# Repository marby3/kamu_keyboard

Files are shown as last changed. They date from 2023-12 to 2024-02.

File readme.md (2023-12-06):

# Kamu Keyboard 

Kamu Keyboardは分割型の10%カラム・スタッガードキーボードです。  
キーボードを組み立てるために必要な部品は以下の通りです。  

- PCB   x1  
- ProMicro  x2  
- TRRSジャック  x2  
- タクトスイッチ    x2  
- スイッチソケット（Cherry MX） x10  
- OLED（オプション）    x2  
- アクリルプレート 2mm（トップ）    x2
- アクリルプレート 2mm（ボトム）    x2
- アクリルプレート 2mm（カバー）    x2
- M2 ネジ（皿ねじ以外で3mm以上5mm以下で）   x28
- M2 スペーサー 7mm x14

PCBは[kamu_keyboard_pcb]>[gerber]内にあるファイルをJLCPCBやElecrowなどで発注することで注文が可能です。（ZIPファイルがあるのでそれを利用すると良いです）  

アクリルプレートは[kamu_keyboard_pcb]>[Plate_data]内にあるファイルを遊舎工房やElecrowなどのアクリルカットサービスが可能な業者にて加工をお願いしてください。  
1つのファイルで1セット分が加工できるようにファイルを用意しています。  

組み立て手順は[Kamu Keyboardの組み立て方](/build_guide/buildguide.md)をご覧ください。

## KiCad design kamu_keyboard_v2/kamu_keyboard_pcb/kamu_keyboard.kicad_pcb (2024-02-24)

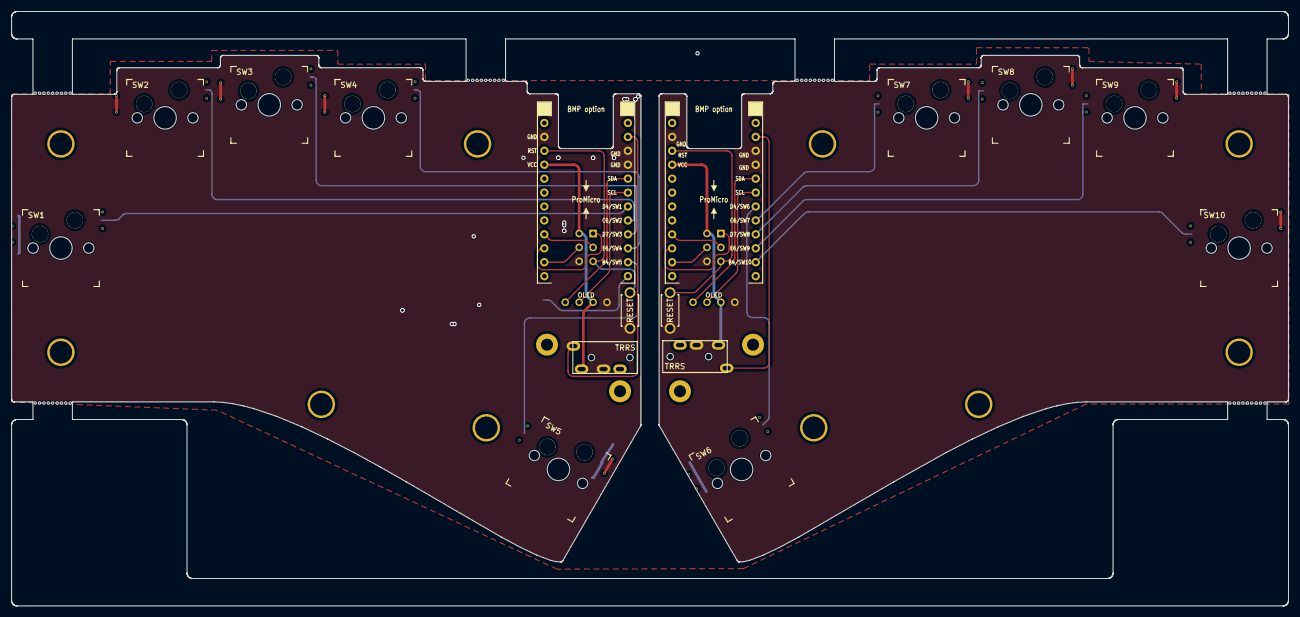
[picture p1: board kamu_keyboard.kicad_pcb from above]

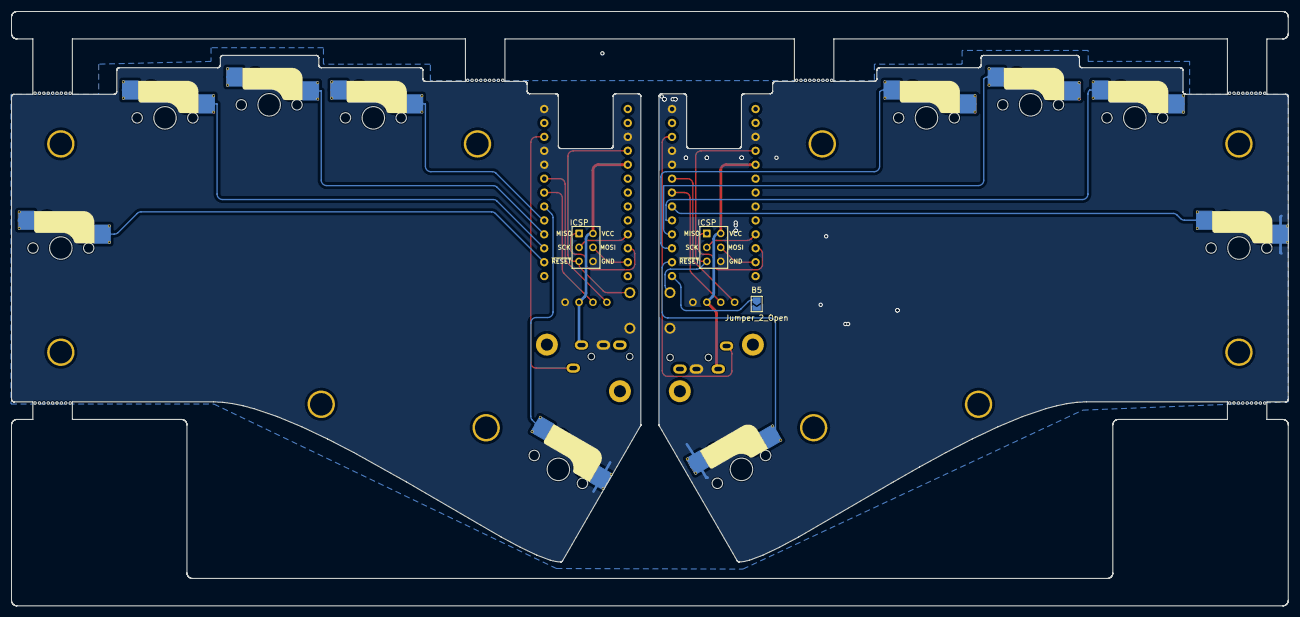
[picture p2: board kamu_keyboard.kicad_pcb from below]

Board: 2 copper layers, 232.9 x 108.4 mm, 21 parts (13 on the bottom side), 27 nets.

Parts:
J1, J3: OLED
J2, J4: ICSP
J5, J6: TRRS; MJ-4PP-9_1side
JP1: Jumper_2_Open; SolderJumper-2_P1.3mm_Open_TrianglePad1.0x1.5mm
RSW1, RSW2: SW_PUSH; ResetSW_1side
SW1, SW2, SW3, SW4, SW5, SW6, SW7, SW8, SW9, SW10: SW_PUSH; CherryMXSwitch_hotswap_1_00u
U1, U2: ProMicro; Board_BMP_Flip_Side

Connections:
/L_Data: J5.S, U1.2 (RX1/D2)
/L_MISO: J2.1, U1.15 (B3/14)
/L_MOSI: J2.4, U1.14 (B2/16)
/L_RST: J2.5, RSW1.2, U1.22 (RST)
/L_SCL: J1.2 (SCL), U1.6 (3/D0/SCL)
/L_SCLK: J2.3, U1.16 (B1/15)
/L_SDA: J1.1 (SDA), U1.5 (2/D1/SDA)
/L_push1: SW1.2, U1.7 (4/D4)
/L_push2: SW2.2, U1.8 (5/C6)
/L_push3: SW3.2, U1.9 (6/D7)
/L_push4: SW4.2, U1.10 (7/E6)
/L_push5: SW5.1, U1.11 (8/B4)
/L_side: JP1.1 (A), U1.12 (9/B5)
/R_Data: J6.S, U2.2 (RX1/D2)
/R_MISO: J4.1, U2.15 (B3/14)
/R_MOSI: J4.4, U2.14 (B2/16)
/R_RST: J4.5, RSW2.1, U2.22 (RST)
/R_SCL: J3.2 (SCL), U2.6 (3/D0/SCL)
/R_SCLK: J4.3, U2.16 (B1/15)
/R_SDA: J3.1 (SDA), U2.5 (2/D1/SDA)
/R_push6: SW6.2, U2.7 (4/D4)
/R_push7: SW7.1, U2.8 (5/C6)
/R_push8: SW8.1, U2.9 (6/D7)
/R_push9: SW9.1, U2.10 (7/E6)
/R_push10: SW10.1, U2.11 (8/B4)
GND: J1.4 (GND), J2.6, J3.4 (GND), J4.6, J5.R1, J6.R1, JP1.2 (B), RSW1.1, RSW2.2, SW1.1, SW2.1, SW3.1, SW4.1, SW5.2, SW6.1, SW7.2, SW8.2, SW9.2, SW10.2, U1.3 (GND), U1.4 (GND), U1.23 (GND), U1.26 (Bat-), U2.3 (GND), U2.4 (GND), U2.23 (GND), U2.26 (Bat-)
VCC: J1.3 (VCC), J2.2, J3.3 (VCC), J4.2, J5.T, J6.T, U1.21 (VCC), U2.21 (VCC)

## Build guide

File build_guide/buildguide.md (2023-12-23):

# Kamu Keyboardの組み立て方  

本ガイドはKamu KeyboardのV1を使用して作成されています。  
基本的な組み立て手順は同一ですので、部品を置き換えて組み立てをお願いします。  

# 必要部品  
- PCB   x1  
- ProMicro  x2  
- TRRSジャック  x2  
- タクトスイッチ    x2  
- スイッチソケット（Cherry MX） x10  
- OLED（オプション）    x2  
- アクリルプレート 2mm（トップ）    x2
- アクリルプレート 2mm（ボトム）    x2
- アクリルプレート 2mm（カバー）    x2
- M2 ネジ（皿ねじ以外で3mm以上5mm以下で）   x28
- M2 スペーサー 7mm x14

# 組み立て手順  

## 01. PCBの端材部分をカットする  
PCBの表面はこちらです。  
画像01  
PCBの裏面はこちらです。  
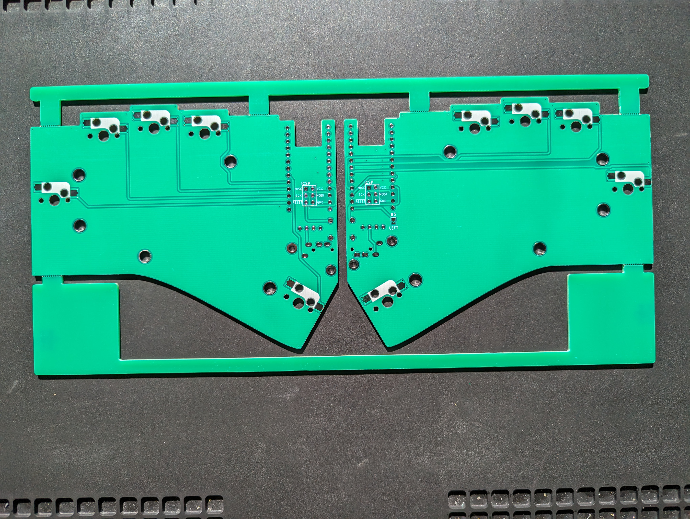
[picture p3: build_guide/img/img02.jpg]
画像02
  

端材部分をカットします。  
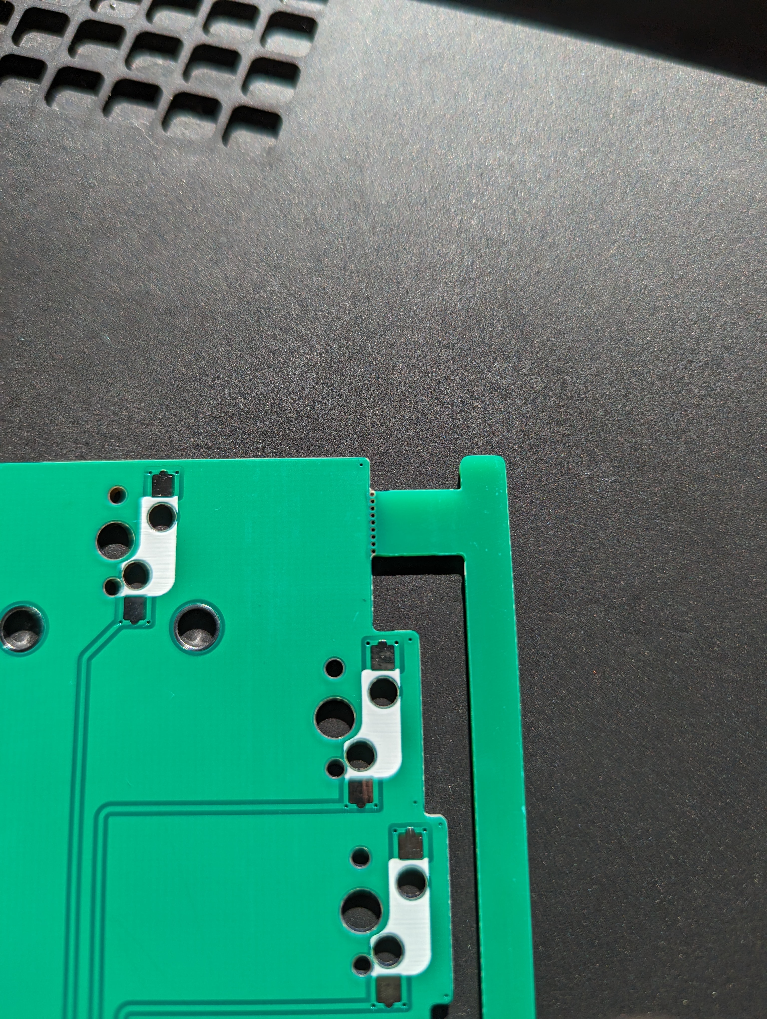
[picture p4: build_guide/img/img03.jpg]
画像03
  
該当箇所をヤスリ等で削ります。  
画像04  
画像05  

## 02. ソケットを半田付けする  
スイッチソケットのパッドに予備半田を行います。  
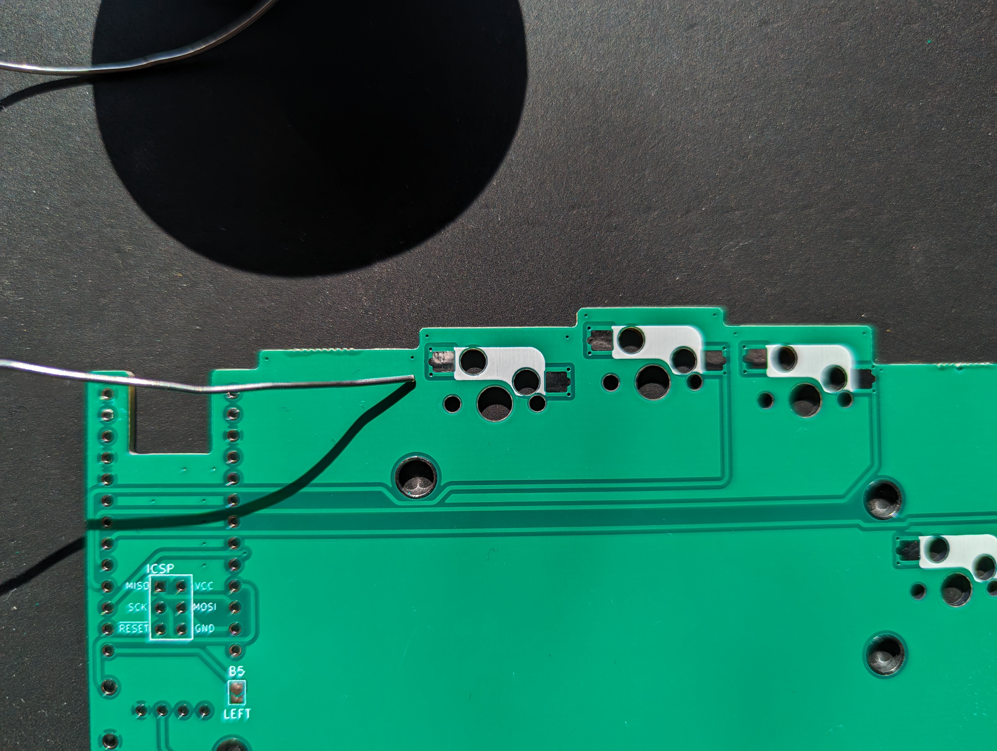
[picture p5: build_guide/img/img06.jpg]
画像06
  
画像07  

ソケットはこのような形状です。  
画像08  

残りを半田付けします。  
（画像はスイッチが取り付けられています）  
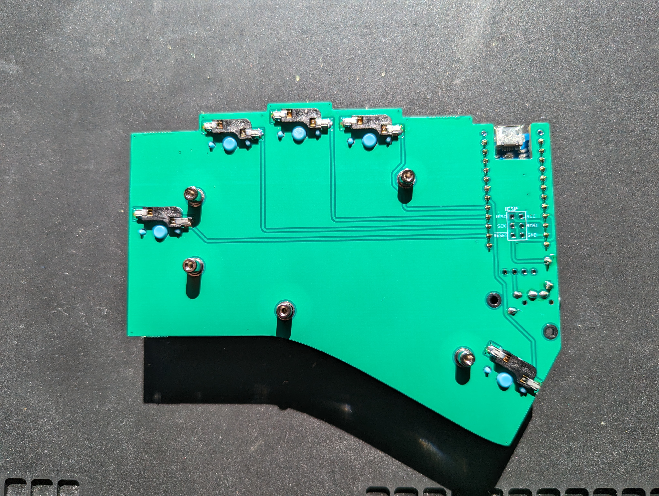
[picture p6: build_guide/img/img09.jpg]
画像09
  

## 03. Pro Microを半田付けする  
コンスルーを取り付けます。  
画像10  
取り付け向きは同じにし、側面の窓は両方とも上側になるようとりつけます。  
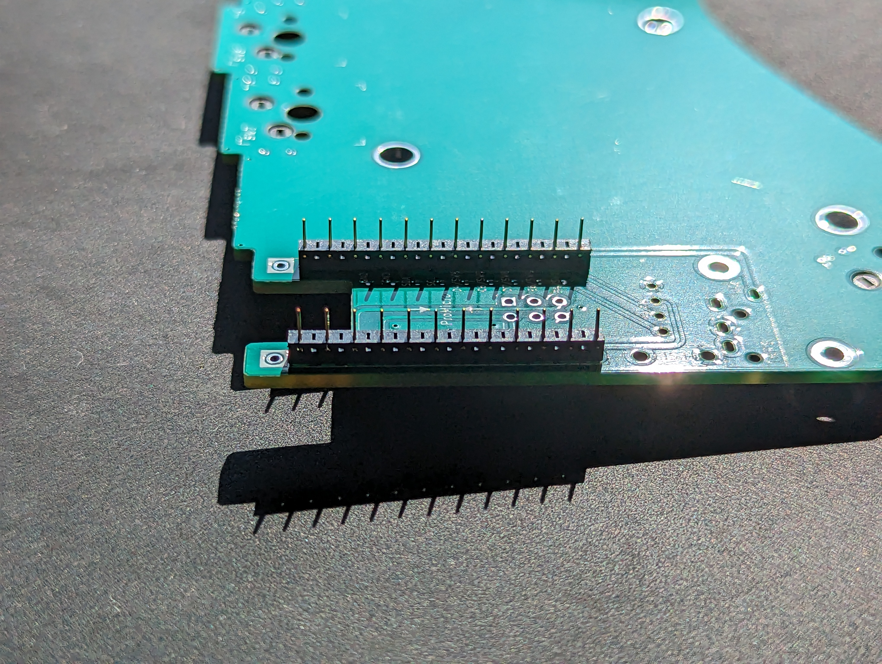
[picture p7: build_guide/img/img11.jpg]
画像11
  

Pro Microはこのような見た目です。  
画像12  
これを先程のコンスルーに差し込みます。  
画像13  
対角線上のピンを最初に固定します。  
画像14  
四隅を固定し、残りすべてのピンを半田付けします。  
画像15  
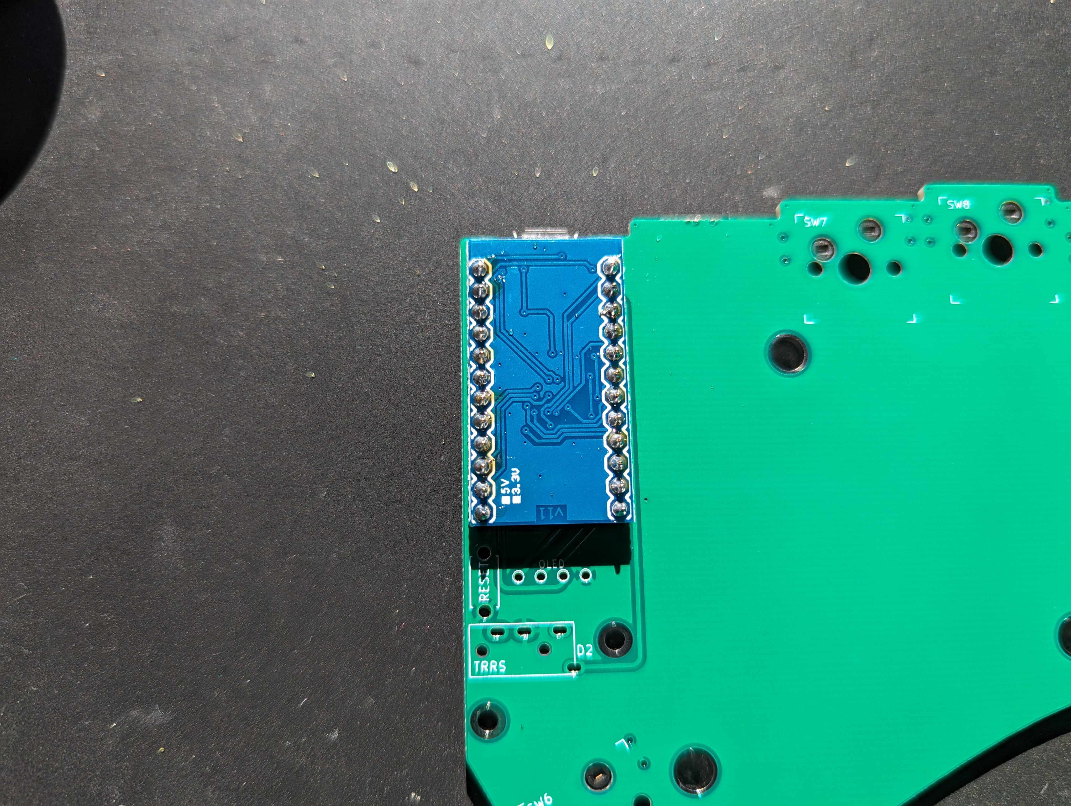
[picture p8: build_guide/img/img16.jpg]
画像16
  

## 04. リセットスイッチとTRRSジャックを半田付けする  
リセットスイッチはこのような見た目です。  
画像17  
TRRSジャックはこのような見た目です。  
画像18  

これらを基板表面に取り付けます。  
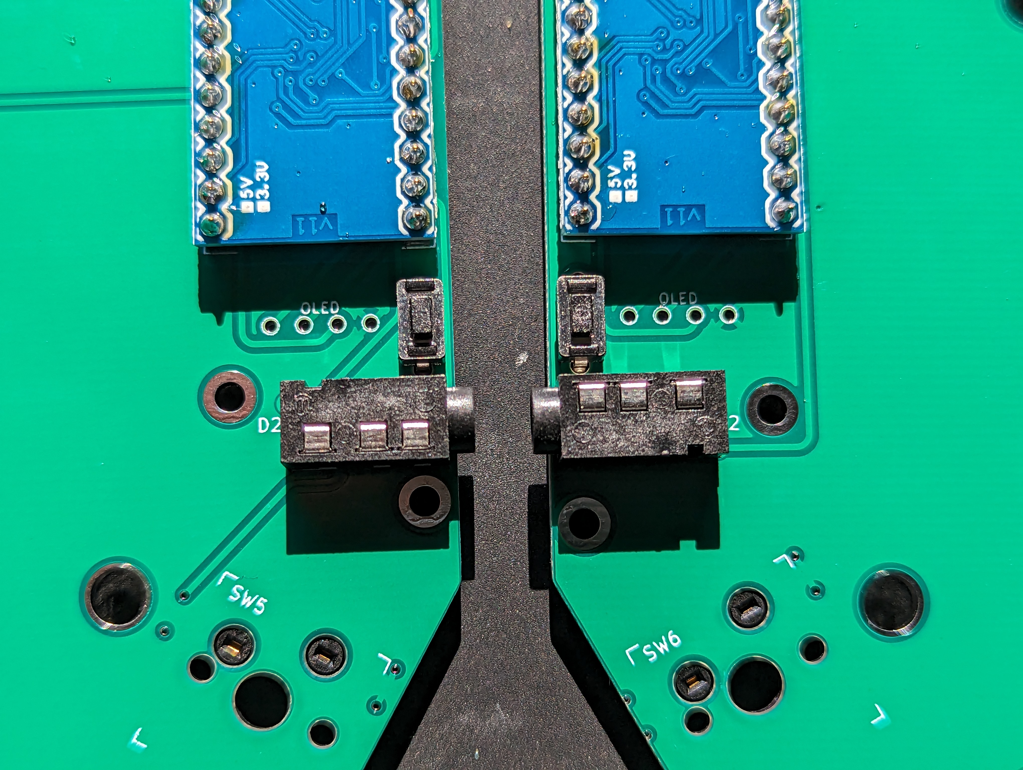
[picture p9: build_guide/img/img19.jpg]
画像19
  
裏面を半田付けします。  
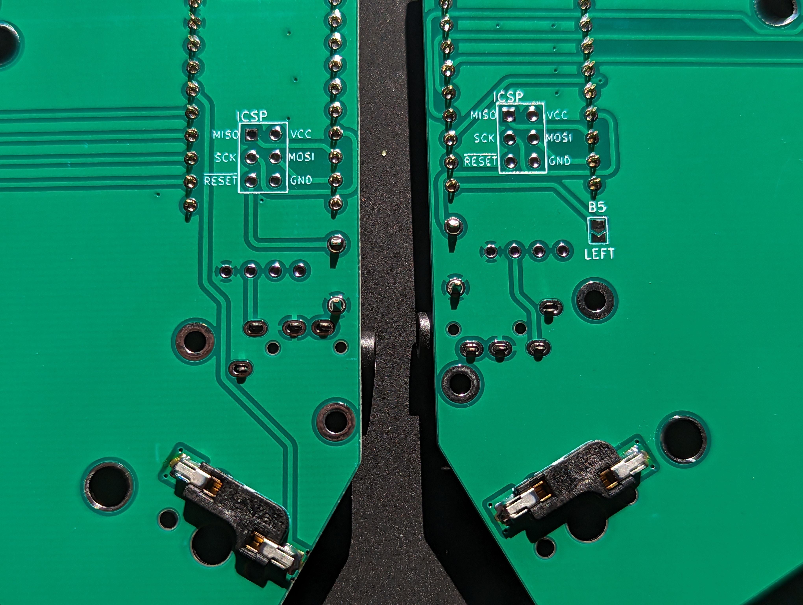
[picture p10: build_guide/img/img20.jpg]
画像20
  
## 05. アクリルプレートの保護シートを剥がし、スイッチを嵌める  
アクリルの保護シートを剥がします。  
画像21  
スイッチをはめ込みます。  
画像22  

## 06. スイッチをPCBに差し込む  
PCBにスイッチを取り付けます。  
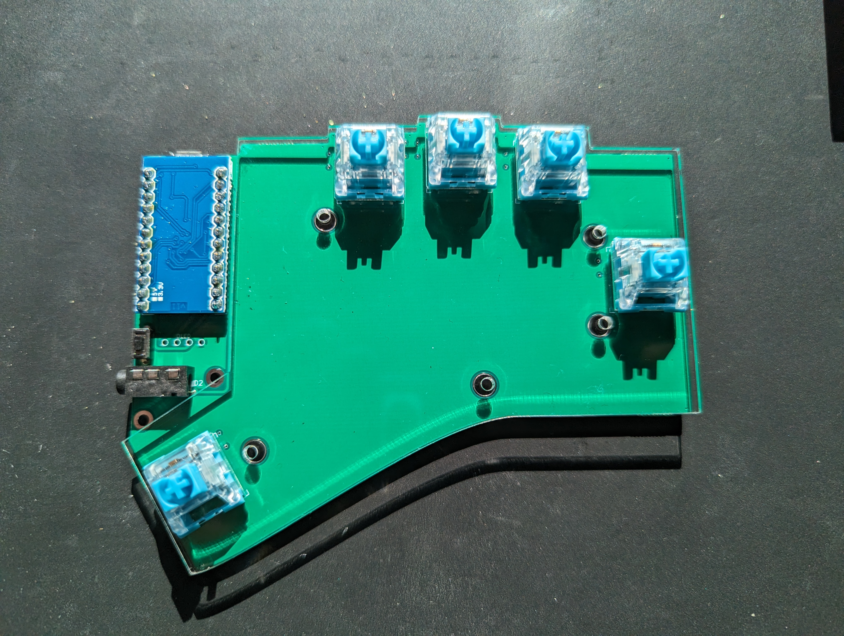
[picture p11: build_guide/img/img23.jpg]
画像23
  
## 07. スペーサーとネジを付け固定する  
スペーサーとネジを取り付け、固定します。  
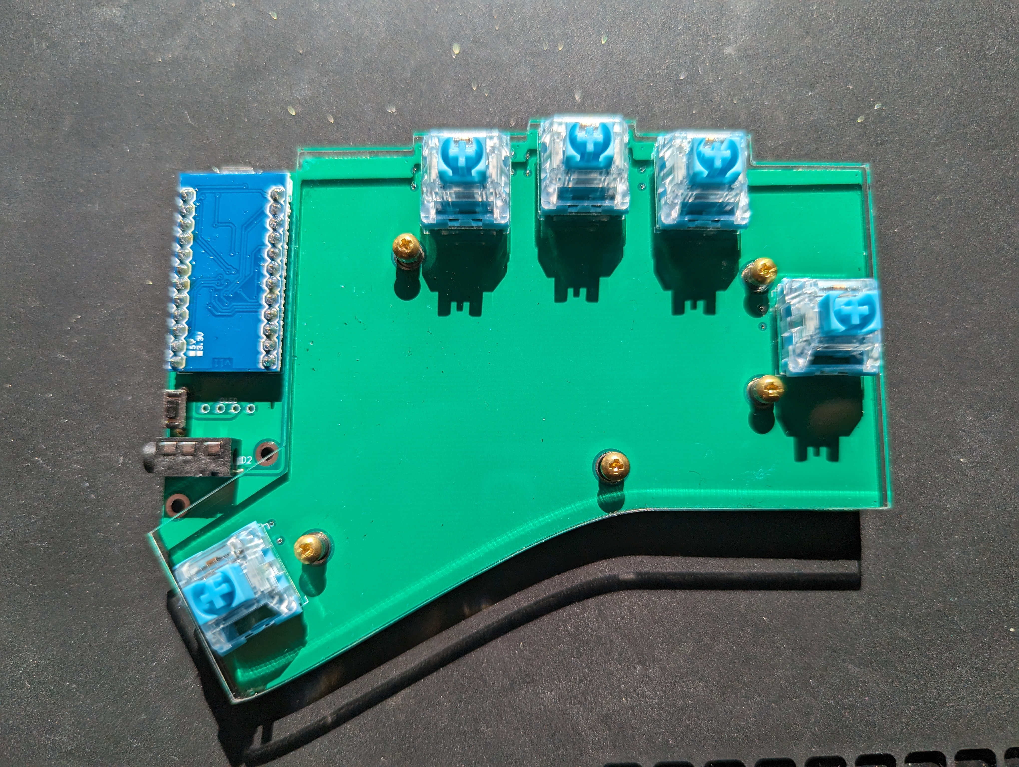
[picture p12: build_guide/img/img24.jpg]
画像24
  

完成！  
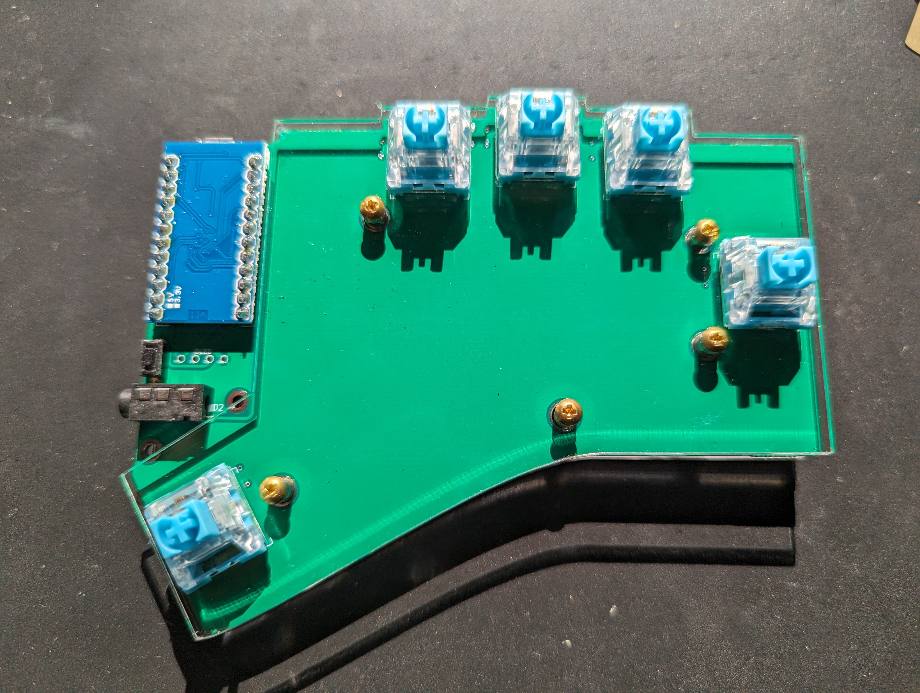
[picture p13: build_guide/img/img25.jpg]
画像25


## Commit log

2023-12-06 データ追加
    [kamu_keyboard.kicad_pcb, kamu_keyboard.kicad_sch]
2024-02-18 トッププレート&ボトムプレートにPCBデザインを追加
    [kamu_keyboard-B_Cu.gbr, kamu_keyboard-B_Mask.gbr, kamu_keyboard-B_Paste.gbr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]
2024-02-24 fix gerber
    [kamu_keyboard-B_Cu.gbr, kamu_keyboard-B_Mask.gbr, kamu_keyboard-B_Paste.gbr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]
